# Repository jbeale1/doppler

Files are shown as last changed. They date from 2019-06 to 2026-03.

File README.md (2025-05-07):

## Doppler Radar object detection and speed measurement

This project uses cheap doppler radar modules: low power, short range motion detectors intended for automatic door openers and similar uses. The HB100 at 10.525 GHz or the smaller, more directional CDM324 at 24 GHz are available on eBay under $10 and Amazon for a bit more. They generate a weak (microphone-level) audio signal output, with a frequency proportional to the speed of the detected object. They can detect people to 25+ feet and cars to 100+ feet. Watch [this video](https://www.youtube.com/watch?v=r2NwtRPYWK4) to hear the signal as cars pass. A simple aluminum-foil horn antenna reduces sensitivity towards the side and back, and extends this range somewhat. Below is a CDM324 sensor in a small 3D printed conical horn, before applying the copper-foil tape for the reflector. The  sensor PCB is about 1 inch square. The horn front opening is 3 inches in diameter and when assembled, it picks up SUVs or trucks around 200 feet, somewhat less for small cars.

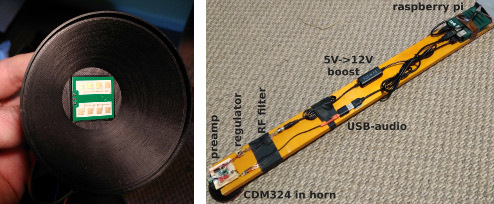
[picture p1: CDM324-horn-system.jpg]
CDM324_horn


When connecting a circuit, be careful because the output pin has a DC bias, and is static sensitive, and they will usually not survive being connected incorrectly. These modules run from +5V but there is no rejection of power-supply noise whatsoever, so it may deliver no useful signal with +5V straight from a USB or switching power supply. I suspect that is why many people quickly give up on them, not realizing how critical it is to have RF-clean power.  It works OK on battery power (4 NiMH AA cells is close enough to 5V), or a low-noise, RF-filtered supply. I start with a cheap noisy 5V->12V booster ("KUNCAN 5ft USB 5v to DC 12v Step Up") and put that 12V through several LC filters and ferrite beads, into a LM78L05 linear regulator to deliver reasonably clean +5V. The CDM324 draws around 30 mA at 5V.  Note the modules have a simple diode detector that will also respond to any strong local RF, so keep it away from your wifi hub and cellphone. There is a clear description of how the CDM324 works at [The Signal Path](http://thesignalpath.com/blogs/2018/08/12/tutorial-experiment-teardown-of-a-24ghz-doppler-radar-module/).

You can run the weak doppler output signal through a preamp (eg. opamp OPA209A, gain of 200x = 46 dB) and into a USB audio adaptor to get data into a Raspberry Pi (or any old phone/tablet/computer). On a Pi or other Linux based machine, **ffmpeg** can record the frequency signals into mp3 or wave files, and **sox** can generate a spectrogram. A car passing by at a constant speed will produce a curved line on the spectogram, because the signal is proportional to the relative *radial* velocity of the car at any given time. In other words, that part of the total velocity going directly towards or away from the sensor. 

For example, if the radar sensor sits by the side of the road looking to the right, and a car approaches from the right and then passes, at first the car's motion is almost directly towards the sensor (radial velocity ~ total velocity) but then radial velocity drops to zero at the moment it draws even with the sensor and passes by. After that its radial velocity goes negative as it receeds, but meanwhile it has also passed behind the sensor and out of the radar antenna pattern, so the signal fades out at some point before reaching a frequency of 0 (not to mention the preamp is AC-coupled). On a two-lane road, signals from oncoming traffic in the far lane fade into the noise sooner than with-traffic in the near lane, since cars in the far lane remain farther away as they pass.

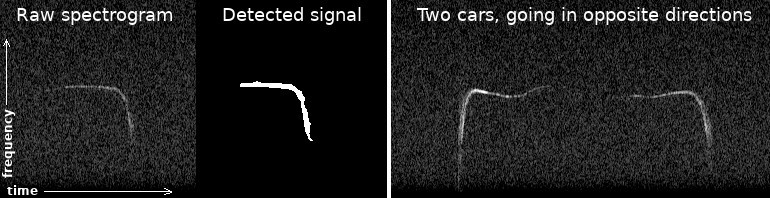
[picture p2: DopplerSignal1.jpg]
CarDopplerSignal


These cheap radar sensors do not have an I+Q output but just a magnitude output, so you cannot directly tell apart approaching and receeding velocity. However if the sensor is pointed along the road, cars passing by towards the right and left will generate an "L" shaped curve in the spectrum with the horizontal part pointing right and left respectively, as they pass the sensor either at the start or the end of the time they are inside the sensor's field of view (see illustration above). In this way you can still tell the car's direction.  This assumes the car's speed is roughly constant; it can be harder to tell if a car slows down and stops while inside the field of view. Below is the signal from an approaching car which slows down nearly to a stop, then speeds up as it passes by. The first dip and rise is due to the car's actual speed changing, while the final dropoff is only from the angle relative to the sensor.

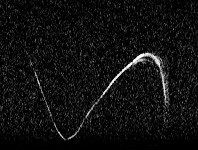
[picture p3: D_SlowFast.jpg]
SlowerThenFaster


If you had two sensors positioned back-to-back on the side of the road, so one was looking to the right and the other to the left, it would be easier to separate a change in speed from a change in heading angle. First one sensor would detect an approaching car until it passed by, and then the other sensor would see it receeding. Below is an illustration of this, where the two sensor outputs are color-coded and combined into one image. The true velocity of the car is most likely to be a smooth curve that bridges above the gap between the red and green curves (right- and left-facing sensor outputs).

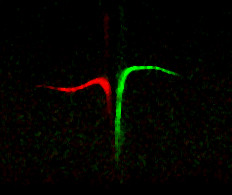
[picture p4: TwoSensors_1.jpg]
TwoSensors


Walkers or joggers generate a distictive wavy pattern (FM signal) in the spectrogram from the ~2 Hz motion of their arms and legs, and of course they move much slower than cars. As cars pass nearby the sensor, reflections from different parts of the rotating wheels generate some velocity spread. The top of the wheel is moving 2X the car speed, while the bottom of the wheel is momentarily near 0 speed. All such effects depend on reflectivity of the various parts so it is less visible on wheel hubs with a smoother profile.  If a vehicle is very close to the sensor while another one passes, you may get a signal from more than one angle at once, as part of the radar energy ping-pongs off one surface and then another.

Given that the green signal is from the left-pointing sensor, you can see below a person walking left to right at a steady pace (here, 4 mph). Later by a truck passes by going the same way. The truck speeds up slightly to 19 mph, then slows down quickly as it departs to the right.  There is a spike in the pedestrian signal just as he passes by. He was holding a cellphone in his hand and this may have been a momentary glint reflecting off the flat metal case.

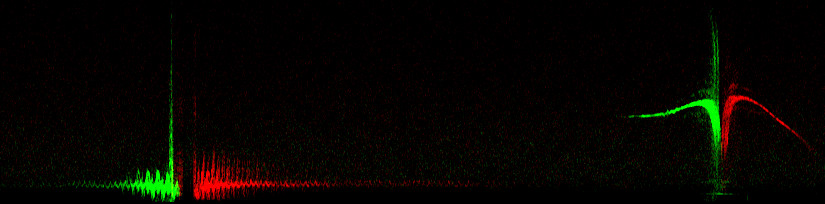
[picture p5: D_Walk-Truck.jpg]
Walk-Truck


If you have a sensor with both I/Q outputs (quadrature) you can directly detect the difference between motion toward and away from the sensor. This plot shows a spectrogram including negative frequencies, of the complex I/Q signal from a YH-24G01 24GHz module. This is me walking about 11 meters away and then back. I was careful to walk centered on-axis along the relatively tight antenna pattern of this module. The code which made this plot is "plotIQ.py" in this github directory.

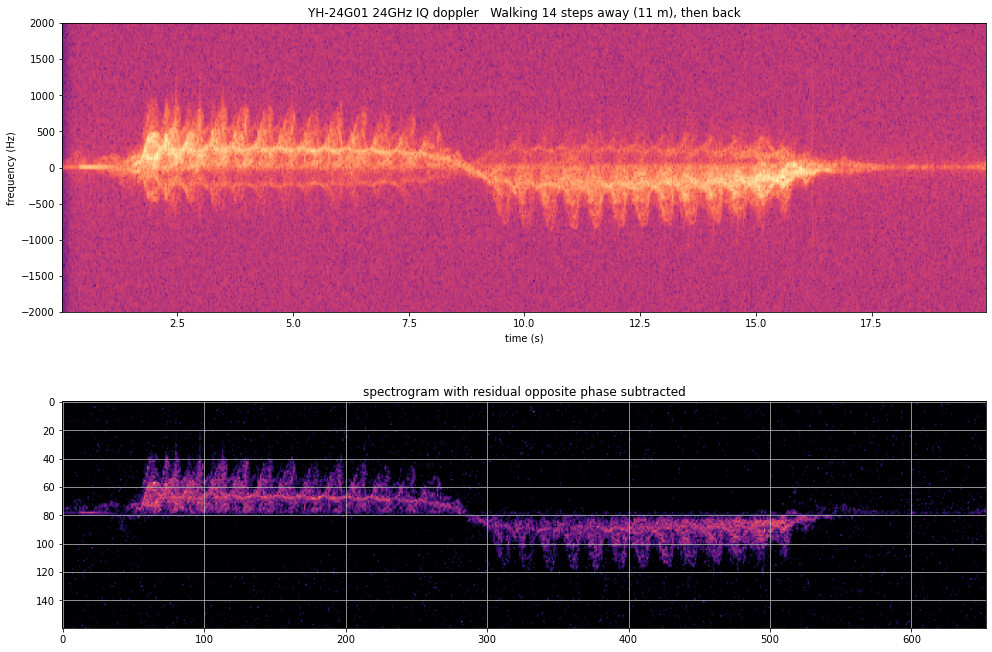
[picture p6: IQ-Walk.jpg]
Walk-IQ


The statistics of vehicle speeds over a day, on this particular road, is not well fitted to a single gaussian or normal distribution. There are a few cases at the high end around 70 km/h or 43 mph that are improbable outliers vs. the main population at 43 +/- 7 km/h  (or 27 mph +/- 4.4 mph).
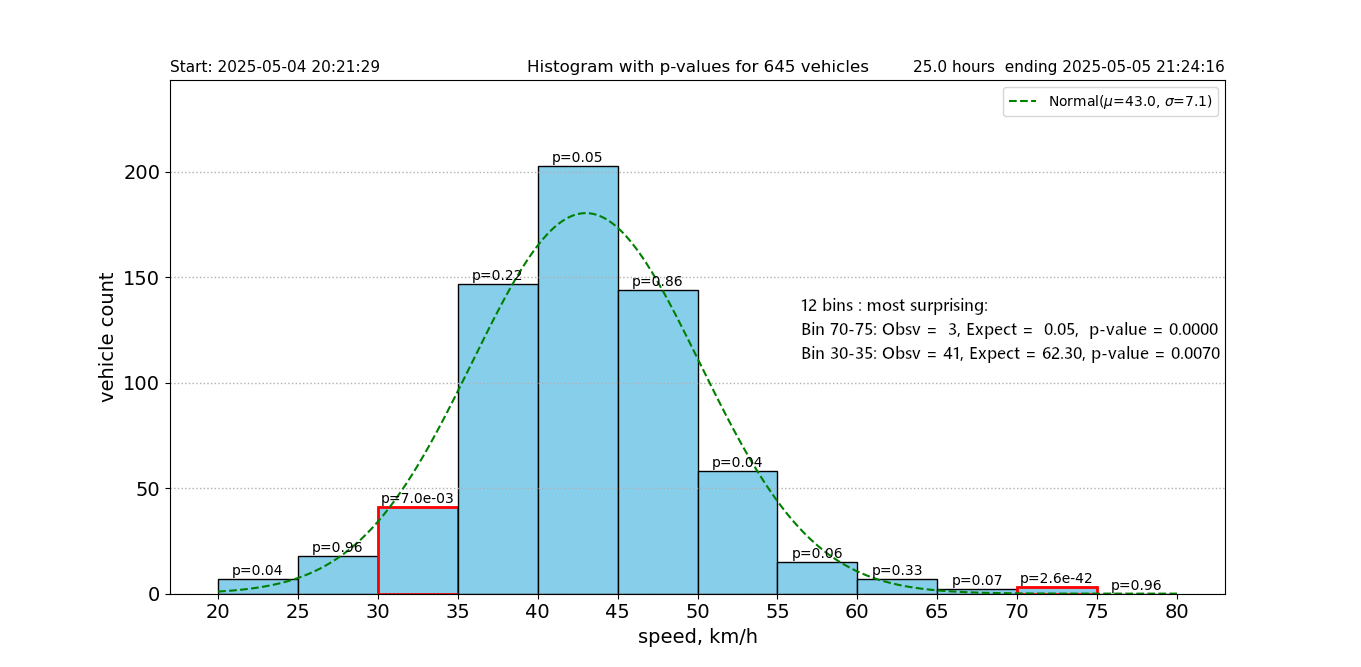
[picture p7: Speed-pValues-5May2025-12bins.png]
Speed-Histogram


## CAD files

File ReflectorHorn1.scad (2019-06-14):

// ===  rect -> circular horn antenna
// ===  J.Beale August 23 2018

e1 = 0.2;       // tolerance for ID shrink
OD1 = 75.4+e1;	// OD of "3-inch" round retroreflector
RFZ2 = 4.8;    // full z-height of round reflector
RFZ = 3.1;     // z-height step of round ref. edge
RFWT = 1;     // front lip wall thickness
ODFL = OD1 + (RFWT*2);  // OD of front lip
RFZE = 2;      // extra Z overlap with cone

e = 0.4;        // extra ID for slop
TXD = 25.2+e;	// Transmitter PCB X dim
TYD = 25.2+e;   // Transmitter PCB Y DIM
// OA1 = 36;     // opening angle of horn in degrees
OA1 = 55;     // opening angle of horn in degrees
TH1 = 0.8;    // wall thickness of horn

PCBZ = 6.8;     // z-height of PCB mounting
phX = 10;       // length of hole for PCB pins
phY = 4;        // width of hold for pins
phZ = 50;       // height of cutout block for pins
phYT = -10.4;   // Y axis translation of hole from center

PI = 3.14159265358979;  // constant
SQR2 = sqrt(2);  // constant
OD2 = TXD * SQR2;  // enclosing circle for PCB

OA1R = OA1 * PI / 180;  // angle in radians
ZH0 = (OD1/2) / tan(OA1/2);
ZHd = (OD2/2) / tan(OA1/2);
Zd = 3;  // vertical shift to create wall thickness
bt = 0.6; // bottom wall thickness
// =========================================
fn = 100;	// number of facets on cylinder
eps = 0.1; // a small number

// block to remove hole for PCB pins (3x on 0.1" centers)
module pcbHole() {
    translate([0,phYT,0])
      cube([phX,phY,phZ],center=true);
}

module cone1() {
    // front lip to hold edge of round cover
 difference() {
  translate([0,0,ZH0-ZHd-Zd-RFZE]) cylinder(d = ODFL, h = RFZ+RFZE, $fn=fn);   
  translate([0,0,ZH0-ZHd-Zd-eps]) cylinder(d = OD1, h = RFZ+2*eps, $fn=fn);   
 }

  translate([0,0,-ZHd-Zd+3.5]) {
    cylinder(d1 = 0, d2=ODFL, h=ZH0-5, center=false,$fn=fn); // outer conical shell
  }
}

module cone2() {
  translate([0,0,-ZHd]) {
    cylinder(d1 = 0, d2=OD1, h=ZH0, center=false,$fn=fn); // inner conical shell
  }
}

module shell1() {
    difference() {
        cone1();
        cone2();
    }
}

module bottom1() {
  translate([0,0,-PCBZ/2]) {
    cylinder(d=TXD*SQR2+Zd, h=PCBZ, center=true,$fn=fn); 
      // bottom pcb holder side  
  }
    
}

// ========================================

// round cover in front
// color("red") { translate([0,0,5+ZH0-ZHd-Zd]) cylinder(d = OD1, h = RFZ, $fn=fn);    }



module assy1() {


// main cone
intersection() {
  translate([0,0,+OD1/2]) cube([ODFL,ODFL,OD1],center=true);
  shell1();
 }

// bottom PCB holder    
difference() {
  bottom1();  // enclosing cylinder
  translate([0,0,bt-PCBZ/2]) cube([TXD,TYD,PCBZ],center=true); // pocket
  pcbHole();  // hole for pins
}
 
} // assy1()

intersection() {
  assy1();
  // translate([0,-100,-100])  cube([200,200,200]);
    
}

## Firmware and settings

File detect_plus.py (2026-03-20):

#!/usr/bin/env python3
"""
detect_plus.py  v1.12

Detects a "boxed plus" marker: a dark outer rectangle enclosing four white
corner squares arranged in a 2x2 grid, with the + shape formed by the dark
cross arms between them.

Detection pipeline:
  1. Preprocess: scale to 50%, light Gaussian blur, mild unsharp mask (USM)
     — used only for the coarse search step.
  2. Coarse: black-hat morphology on the 50% proc image finds dark-rectangle
     candidates in the road zone.
  3. Fine (_fine_detect_plus): for each candidate, crops the full-resolution
     gray image and applies adaptive threshold across a range of block sizes
     to isolate exactly four white corner squares as clean blobs.  The best-
     scoring 2x2 group is selected, subpixel corner refinement is applied to
     all 16 corners (4 squares x 4 corners), and the mean of the 4 inner
     corners gives an initial centre estimate.  The found group must be close
     to the candidate location and pass a size-uniformity check.
  4. Refine (refine_center_by_lines): re-detects the four white squares at
     full resolution using an adaptive block size scaled to the marker's
     apparent size.  Samples edge-gradient positions along each of the 8
     inner square edges (right/bottom of TL, left/bottom of TR, right/top
     of BL, left/top of BR), fits strictly parallel line pairs, and returns
     the mean of the 4 arm-line intersection points as the refined centre.
     Geometry sanity checks (square size uniformity, arm gap validity, and
     spatial ordering) reject false positives before the result is accepted.
  5. All returned coordinates are in original full-image pixels.

Can be run standalone:
    python detect_plus.py image.jpg [image2.jpg ...] [--verbose]

Or imported and called:
    from detect_plus import find_plus_markers
    results = find_plus_markers(gray, verbose=False)
"""

VERSION = "1.12"

import cv2
import numpy as np
import sys, os, argparse
from itertools import combinations

# ── Preprocessing ─────────────────────────────────────────────────────────────

def preprocess(gray, scale=0.5, blur_r=1, usm_radius=1, usm_amount=0.3):
    """
    Prepare image for plus-marker detection:
      1. Scale to `scale` (default 0.5 = 50%)
      2. Light Gaussian blur (blur_r pixel radius)
      3. Unsharp mask (usm_radius, usm_amount)

    The USM step dramatically clarifies the four white corner squares as
    isolated bright blobs on the dark + rectangle background.
    Returns the processed image at reduced scale.
    """
    small = cv2.resize(gray, None, fx=scale, fy=scale,
                       interpolation=cv2.INTER_AREA)
    if blur_r > 0:
        k = blur_r * 2 + 1
        small = cv2.GaussianBlur(small, (k, k), 0)
    blur_usm  = cv2.GaussianBlur(small, (usm_radius * 2 + 1, usm_radius * 2 + 1), 0)
    sharpened = cv2.addWeighted(small, 1.0 + usm_amount, blur_usm, -usm_amount, 0)
    return sharpened

# ── Geometry helpers (mirrors detect_marker.py) ──────────────────────────────

def _order_rect(pts):
    """Order 4 points as TL, TR, BR, BL."""
    pts = np.array(pts, dtype=np.float32)
    pts = pts[np.argsort(pts[:, 1])]
    top = pts[:2][np.argsort(pts[:2, 0])]
    bot = pts[2:][np.argsort(pts[2:, 0])]
    return np.array([top[0], top[1], bot[1], bot[0]], dtype=np.float32)


def _subpix_corners(gray, box, win=4):
    """Refine corner positions to sub-pixel accuracy."""
    h, w = gray.shape
    pts = np.clip(box, win + 1, min(h, w) - win - 2).astype(np.float32).reshape(-1, 1, 2)
    try:
        r = cv2.cornerSubPix(
            gray, pts, (win, win), (-1, -1),
            (cv2.TERM_CRITERIA_EPS + cv2.TERM_CRITERIA_MAX_ITER, 40, 0.001))
        return r.reshape(-1, 2)
    except cv2.error:
        return box


def _rect_corners_from_contour(c):
    """Return 4 ordered corners from a contour via minAreaRect."""
    rect = cv2.minAreaRect(c)
    box  = cv2.boxPoints(rect).astype(np.float32)
    return _order_rect(box)


# ── Coarse search ─────────────────────────────────────────────────────────────

def _coarse_candidates(proc, scale=0.5, tophat_k=5, thresh=15,
                       min_area=8, max_area=600, max_aspect=1.8):
    """
    Find candidate dark-rectangle centers in the preprocessed (50%) image
    using black-hat morphology. Returns (cx, cy) in ORIGINAL full-image coords.
    """
    kernel   = cv2.getStructuringElement(cv2.MORPH_RECT, (tophat_k, tophat_k))
    blackhat = cv2.morphologyEx(proc, cv2.MORPH_BLACKHAT, kernel)
    _, th    = cv2.threshold(blackhat, thresh, 255, cv2.THRESH_BINARY)

    contours, _ = cv2.findContours(th, cv2.RETR_EXTERNAL, cv2.CHAIN_APPROX_SIMPLE)
    hits = []
    for c in contours:
        area = cv2.contourArea(c)
        if not (min_area < area < max_area):
            continue
        rect = cv2.minAreaRect(c)
        rw, rh = rect[1]
        if rw < 1 or rh < 1:
            continue
        if max(rw, rh) / min(rw, rh) > max_aspect:
            continue
        cx, cy = rect[0]
        # Convert back to full-image coords
        hits.append((cx / scale, cy / scale))
    return hits


# ── Fine detection ────────────────────────────────────────────────────────────

def _fine_detect_plus(proc, cx_full, cy_full, scale=0.5, pad_full=120,
                      verbose=False):
    """
    Detect a boxed-plus marker near (cx_full, cy_full) in full-image coords.

    Despite the parameter name, `proc` is the 50%-scale preprocessed image
    used only to define the crop region; all detection runs on the full-
    resolution gray image passed to find_plus_markers (via gray captured in
    the closure — or via the `proc` image when called directly for testing).

    Crops a pad_fullxpad_full region around the candidate, applies adaptive
    threshold across block sizes (11,15) at 50% scale to find four white-
    square blobs in a 2x2 arrangement, scores all C(12,4)=495 quad
    combinations per threshold, subpixel-refines all 16 corners, and returns
    a result dict with centre, apparent size, and geometry.  The found group
    must be within 80% of pad_full of the candidate centre.

    All returned coordinates are in original full-image pixels.
    """
    h_proc, w_proc = proc.shape
    cx  = cx_full * scale
    cy  = cy_full * scale
    pad = int(pad_full * scale)

    x0 = max(0, int(cx) - pad)
    y0 = max(0, int(cy) - pad)
    x1 = min(w_proc, int(cx) + pad)
    y1 = min(h_proc, int(cy) + pad)
    crop = proc[y0:y1, x0:x1]
    if crop.size == 0:
        return None
    off_proc = np.array([x0, y0], dtype=np.float32)

    # Quick pre-check on first threshold: if there aren't at least 4 small
    # similarly-sized blobs, skip this candidate entirely — it can't be a + box.
    adapt0 = cv2.adaptiveThreshold(crop, 255,
                                    cv2.ADAPTIVE_THRESH_GAUSSIAN_C,
                                    cv2.THRESH_BINARY, 11, -5)
    ctrs0, _ = cv2.findContours(adapt0, cv2.RETR_EXTERNAL,
                                 cv2.CHAIN_APPROX_SIMPLE)
    small_blobs = [(cv2.contourArea(c), cv2.minAreaRect(c))
                   for c in ctrs0
                   if 5 < cv2.contourArea(c) < 800]
    small_blobs = [(a, r) for a, r in small_blobs
                   if r[1][0] >= 2 and r[1][1] >= 2
                   and max(r[1]) / min(r[1]) <= 3.0]
    if len(small_blobs) < 4:
        return None
    # Check uniformity: largest/smallest area ratio among top-4
    top4_areas = sorted([a for a,r in small_blobs], reverse=True)[:4]
    if top4_areas[-1] < 1 or top4_areas[0] / top4_areas[-1] > 8.0:
        return None

    # Adaptive threshold at 50% scale: sweep (block, C) pairs.
    # block=11 and block=15 are appropriate for white squares that are ~7-15px
    # at 50% scale (marker at 13-20m distance).  The best-scoring valid 2x2
    # group across all threshold settings is kept.
    best_group = None
    best_score = -1

    for block, C in [(11, 5), (15, 5), (11, 8), (15, 8)]:
        adapt = cv2.adaptiveThreshold(crop, 255,
                                       cv2.ADAPTIVE_THRESH_GAUSSIAN_C,
                                       cv2.THRESH_BINARY, block, -C)
        ctrs, _ = cv2.findContours(adapt, cv2.RETR_EXTERNAL,
                                    cv2.CHAIN_APPROX_SIMPLE)
        candidates = []
        for c in ctrs:
            area = cv2.contourArea(c)
            if not (5 < area < 2000):
                continue
            rect = cv2.minAreaRect(c)
            rw, rh = rect[1]
            if rw < 2 or rh < 2:
                continue
            if max(rw, rh) / min(rw, rh) > 3.0:
                continue
            candidates.append((area, rw, rh, rect[0], c))

        if len(candidates) < 4:
            continue

        top = sorted(candidates, key=lambda x: -x[0])[:12]
        for quad in combinations(range(len(top)), 4):
            group   = [top[k] for k in quad]
            centers = np.array([r[3] for r in group])
            xs = np.sort(centers[:, 0])
            ys = np.sort(centers[:, 1])
            x_spread = xs[3] - xs[0]
            y_spread = ys[3] - ys[0]
            if x_spread < 3 or y_spread < 3:
                continue
            # 2x2: gap between inner pair > 15% of spread
            if (xs[2]-xs[1]) < 0.15*x_spread or (ys[2]-ys[1]) < 0.15*y_spread:
                continue
            # Roughly square arrangement
            if max(x_spread, y_spread) / max(min(x_spread, y_spread), 1) > 3.5:
                continue
            # Similar areas
            areas = [r[0] for r in group]
            if max(areas) / max(min(areas), 1) > 3.0:
                continue
            # Similar widths
            widths = [max(r[1], r[2]) for r in group]
            if max(widths) / max(min(widths), 1) > 2.0:
                continue
            # Gap between children should be similar to child size
            # (arm width ≈ white square size in a well-designed + box)
            child_w = np.mean([max(r[1],r[2]) for r in group])
            child_h = np.mean([min(r[1],r[2]) for r in group])
            x_gap = xs[2] - xs[1]
            y_gap = ys[2] - ys[1]
            if not (0.3 < x_gap/max(child_w,1) < 5.0):
                continue
            if not (0.3 < y_gap/max(child_h,1) < 5.0):
                continue

            mean_area   = np.mean(areas)
            uniformity  = min(areas) / max(max(areas), 1)
            squareness  = min(x_spread, y_spread) / max(max(x_spread, y_spread), 1)
            score = mean_area*10 + uniformity*500 + squareness*200

            if score > best_score:
                best_score = score
                best_group = group

    if best_group is None:
        return None

    # The group's centre must be near the candidate location
    group_cx = np.mean([r[3][0] for r in best_group]) + x0
    group_cy = np.mean([r[3][1] for r in best_group]) + y0
    if abs(group_cx - cx_full) > pad * 0.8 or abs(group_cy - cy_full) > pad * 0.8:
        return None

    # Order spatially: by (y-bucket, x)
    best_group = sorted(best_group, key=lambda r: (round(r[3][1]/3), r[3][0]))

    child_corners_list = []
    for _, rw, rh, (rcx, rcy), c in best_group:
        box      = _rect_corners_from_contour(c)
        ref_proc = _subpix_corners(crop, box) + off_proc
        ref_full = ref_proc / scale
        child_corners_list.append(ref_full)

    all_corners = np.vstack(child_corners_list)   # 16x2 full-image coords
    child_sizes = [np.linalg.norm(c[1]-c[0]) for c in child_corners_list]
    half_csize  = np.mean(child_sizes) * 0.5

    x_min = all_corners[:,0].min() - half_csize
    x_max = all_corners[:,0].max() + half_csize
    y_min = all_corners[:,1].min() - half_csize
    y_max = all_corners[:,1].max() + half_csize
    outer_corners = np.array([[x_min,y_min],[x_max,y_min],
                               [x_max,y_max],[x_min,y_max]], dtype=np.float32)

    # apparent_px and wh_ratio based on child-centre span, not the padded outer
    # box.  The centre span scales cleanly with camera distance and is
    # independent of the half_csize padding, giving a stable size measure.
    child_centers = np.array([c.mean(axis=0) for c in child_corners_list])
    span_w = child_centers[:,0].max() - child_centers[:,0].min()
    span_h = child_centers[:,1].max() - child_centers[:,1].min()
    apparent_px = (span_w * span_h) ** 0.5
    if (apparent_px < 10 or apparent_px > 40):
        # Reject candidates with implausible apparent size (too small = far away,
        # too large = close but not detected in coarse search).
        return None
    wh_ratio    = span_w / span_h if span_h > 0 else 1.0

    # Center: mean of the 4 inner corners (the corners of each white square
    # that face the arm gap). These subpixel-refine to the arm-crossing point,
    # giving a more accurate center than the mean of all 16 corners.
    # Child order: [TL-child, TR-child, BL-child, BR-child]
    # Inner corner of each: BR(idx 2), BL(idx 3), TR(idx 1), TL(idx 0)
    inner_corners = np.array([
        child_corners_list[0][2],   # TL-child's BR
        child_corners_list[1][3],   # TR-child's BL
        child_corners_list[2][1],   # BL-child's TR
        child_corners_list[3][0],   # BR-child's TL
    ])
    center = inner_corners.mean(axis=0)

    # inner_mean: average gray of the four white squares in preprocessed image
    ccs = np.array([c.mean(axis=0) for c in child_corners_list])
    inner_mean = float(np.mean([
        proc[int(np.clip(pt[1]*scale, 0, h_proc-1)),
             int(np.clip(pt[0]*scale, 0, w_proc-1))]
        for pt in ccs]))

    return {
        'center':        center,
        'outer_corners': outer_corners,
        'child_corners': child_corners_list,
        'all_corners':   all_corners,
        'apparent_px':   apparent_px,
        'wh_ratio':      wh_ratio,
        'inner_mean':    inner_mean,
        'n_children':    4,
    }


# ── Line-intersection centre refinement ──────────────────────────────────────

def _nearest_odd(n):
    """Return nearest odd integer >= n, minimum 3."""
    n = max(3, int(n))
    return n if n % 2 == 1 else n + 1


def refine_center_by_lines(gray, result, hw=4, n_samples=30, trim=0.15):
    """
    Refine the + centre using edge-line fitting from full-resolution square
    bounding boxes.

    Re-detects the four white squares directly on the full-resolution gray
    image using adaptive threshold with block sizes scaled to the marker's
    apparent size (trying 2x and 3x the estimated square width, plus a fixed
    fallback of 21).  One erosion pass ensures bounding boxes sit inside the
    white regions rather than straddling the edges.

    For each of the 8 inner square edges (TL/BL right edges → V_left arm;
    TR/BR left edges → V_right arm; TL/TR bottom edges → H_top arm;
    BL/BR top edges → H_bot arm) samples edge-gradient positions along only
    that square's own span.  Fits a line to each set of samples, then enforces
    strict parallelism within each arm pair by averaging directions.  The
    final centre is the mean of the 4 arm-line intersection points.

    Before accepting the result, applies geometry sanity checks:
      — Four square areas within 4x of each other
      — Four square linear sizes within 2.5x of each other
      — Both arm gaps positive (no overlap)
      — Both arm gaps ≤ 3x average square size
      — H and V arm gaps within 5x of each other
      — Spatial ordering valid: TL.x < TR.x, BL.x < BR.x,
        TL.y < BL.y, TR.y < BR.y

    Returns updated result dict with 'center' replaced by the refined value,
    '_squares_bbox', '_lines', and '_crossings' added.  Returns the original
    result unchanged (without '_squares_bbox') if any check fails, allowing
    the caller to detect and reject the candidate.
    """
    # ── Re-detect white squares at full resolution ────────────────────────────
    gray_full = gray
    cx_est = float(result['center'][0])
    cy_est = float(result['center'][1])

    # Scale the crop pad with the apparent marker size so we always have
    # enough margin even for larger (closer) markers.
    apparent = result.get('apparent_px', 25)
    # apparent_px is child-centre span ≈ arm_pitch.
    # Each white square ≈ apparent/1.5 px wide at full res.
    # Pad needs to comfortably contain 2 squares + arm gap on each side.
    pad = max(55, int(apparent * 3.5))
    x0 = max(0, int(cx_est) - pad)
    y0 = max(0, int(cy_est) - pad)
    x1 = min(gray_full.shape[1], int(cx_est) + pad)
    y1 = min(gray_full.shape[0], int(cy_est) + pad)
    crop = gray_full[y0:y1, x0:x1]
    if crop.size == 0:
        return result

    # Adaptive threshold block size must be larger than one white square
    # but smaller than two squares.  Estimated white square width ≈ apparent/1.5.
    # Try several block sizes from small to large; keep whichever finds 4 squares.
    sq_est = max(5, int(apparent / 1.5))
    block_sizes = sorted(set([
        _nearest_odd(sq_est * 2 + 1),   # ~2x square width
        _nearest_odd(sq_est * 3 + 1),   # ~3x square width
        21,                              # fixed fallback
    ]))

    squares = []
    for block in block_sizes:
        adapt = cv2.adaptiveThreshold(crop, 255,
                                       cv2.ADAPTIVE_THRESH_GAUSSIAN_C,
                                       cv2.THRESH_BINARY, block, -8)
        adapt = cv2.erode(adapt, np.ones((3,3), np.uint8), iterations=1)
        ctrs, _ = cv2.findContours(adapt, cv2.RETR_EXTERNAL,
                                    cv2.CHAIN_APPROX_SIMPLE)
        cands = []
        for c in ctrs:
            area = cv2.contourArea(c)
            if not (20 < area < 5000): continue
            rect = cv2.minAreaRect(c)
            rw, rh = rect[1]
            max_sq_px = sq_est * 3
            if not (4 < rw < max_sq_px and 4 < rh < max_sq_px): continue
            if max(rw, rh) / min(rw, rh) > 2.5: continue
            bx, by, bw, bh = cv2.boundingRect(c)
            cx_f, cy_f = bx + x0 + bw // 2, by + y0 + bh // 2
            cands.append((area, c, rect, bx+x0, by+y0, bw, bh, cx_f, cy_f))
        cands.sort(key=lambda s: (round(s[8] / 10), s[7]))
        if len(cands) >= 4:
            squares = cands
            break   # found enough with this block size

    squares.sort(key=lambda s: (round(s[8] / 10), s[7]))
    if len(squares) != 4:
        return result   # can't refine

    tl, tr, bl, br = squares   # each: (area, c, rect, bx, by, bw, bh, cx, cy)

    # Validate spatial ordering: after sorting, TL must be left of TR,
    # BL must be left of BR, and top row must be above bottom row.
    # If violated the four blobs are not in a genuine 2x2 arrangement.
    if tl[7] >= tr[7]:   # TL.cx >= TR.cx
        return result
    if bl[7] >= br[7]:   # BL.cx >= BR.cx
        return result
    if tl[8] >= bl[8]:   # TL.cy >= BL.cy
        return result
    if tr[8] >= br[8]:   # TR.cy >= BR.cy
        return result

    # ── Sample edge-gradient positions along each inner rectangle edge ────────
    def sample_edge(x_range, y_fixed, direction):
        """
        Vectorized edge-gradient sampler. Builds the full pixel-sample grid
        as numpy arrays instead of a Python loop, making it ~10x faster.
        """
        if direction == 'h':
            p1 = np.array([float(x_range[0]), float(y_fixed)])
            p2 = np.array([float(x_range[1]), float(y_fixed)])
            perp_idx = 1    # gradient measured in y
        else:
            p1 = np.array([float(y_fixed), float(x_range[0])])
            p2 = np.array([float(y_fixed), float(x_range[1])])
            perp_idx = 0    # gradient measured in x
        L = np.linalg.norm(p2 - p1)
        if L < 2: return None
        tang = (p2 - p1) / L

        # Sample positions along the edge
        ts = np.linspace(trim * L, (1 - trim) * L, n_samples)
        base_pts = p1 + ts[:, None] * tang    # (n_samples, 2)

        # Perpendicular offsets
        ds = np.linspace(-hw, hw, hw * 4 + 1)  # (n_d,)
        # All sample coords: (n_samples, n_d, 2)
        if direction == 'h':
            xs = np.round(base_pts[:, 0]).astype(int)             # (n,)
            ys = np.round(base_pts[:, 1:2] + ds[None, :]).astype(int)  # (n, n_d)
            # Clip to image bounds
            xs_c = np.clip(xs, 0, gray_full.shape[1]-1)
            ys_c = np.clip(ys, 0, gray_full.shape[0]-1)
            valid = (ys >= 0) & (ys < gray_full.shape[0])
            vals  = gray_full[ys_c, xs_c[:, None]].astype(float)  # (n, n_d)
        else:
            ys = np.round(base_pts[:, 1]).astype(int)
            xs = np.round(base_pts[:, 0:1] + ds[None, :]).astype(int)
            xs_c = np.clip(xs, 0, gray_full.shape[1]-1)
            ys_c = np.clip(ys, 0, gray_full.shape[0]-1)
            valid = (xs >= 0) & (xs < gray_full.shape[1])
            vals  = gray_full[ys_c[:, None], xs_c].astype(float)

        vals[~valid] = np.nan

        # For each sample position, find edge via gradient-weighted centroid
        pts = []
        for i in range(n_samples):
            v = vals[i]
            ok = ~np.isnan(v)
            if ok.sum() < 3: continue
            v_clean = np.where(ok, v, np.nanmean(v))
            g = np.abs(np.gradient(v_clean))
            if g.sum() < 1: continue
            d_e = float((g * ds).sum() / g.sum())
            pt = base_pts[i].copy()
            pt[perp_idx] += d_e
            pts.append(pt)
        return np.array(pts, np.float32) if len(pts) >= 3 else None

    def fit_line(pts):
        res = cv2.fitLine(pts, cv2.DIST_L2, 0, 0.01, 0.01).flatten()
        return (np.array([float(res[2]), float(res[3])]),
                np.array([float(res[0]), float(res[1])]))

    def avg_dir(d1, d2):
        if np.dot(d1, d2) < 0: d2 = -d2
        d = d1 + d2; return d / np.linalg.norm(d)
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

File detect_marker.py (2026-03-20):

#!/usr/bin/env python3
"""
detect_marker.py  v1.0

Locates printed tracking markers in a full 1920x1080 image for camera calibration purposes.
Uses a coarse-to-fine pipeline:
  1. Coarse (1/4 scale): tophat morphology finds bright compact rectangles
  2. Verify: nested contour structure (CLAHE + multi-threshold) confirms identity
  3. Fine:   homography + subpixel refinement of all features
  4. Validate: white-field uniformity, apparent size, inlier count, road zone

Usage:
    python detect_marker.py image.jpg [image2.jpg ...] [options]
    python detect_marker.py /path/to/frame/directory/ [options]

Options:
    --verbose       Print all candidates and rejection reasons
    --max-dist N    Maximum detection distance in meters (default: 25.0)
    --debug         Save annotated debug crops

Changelog:
    v1.0  Duplicate detection resolved by quality comparison
          (n_inliers then wh_ratio); better of two overlapping
          detections kept; printing deferred until after all candidates
          processed; --road-x argument added.
    v0.9  Width/height ratio check (w/h >= 0.80) rejects tall/narrow spurious
          detections; adaptive ID fill threshold (white_level * 0.70, fallback 110);
          max apparent size raised to 135px; contour scoring uses squareness not area.
    v0.6  Adaptive ID fill threshold; road zone default 33%-48% of height;
          --road-y argument for per-camera tuning; median white_level.
    v0.5  Multi-threshold binary selection; max apparent size gate;
          road-zone center check; relaxed inlier count for small markers;
          directory input support; distance reporting.
    v0.4  White-field uniformity filter (wf_mean, wf_smooth).
    v0.3  CLAHE preprocessing; dense grid fallback; --verbose flag.
    v0.2  SuperPoint-style nested contour hierarchy; homography fit.
    v0.1  Initial release.
"""

VERSION = "1.0"

import cv2
import numpy as np
import sys, os, argparse, warnings
warnings.filterwarnings('ignore', category=RuntimeWarning)

# ── Camera calibration ───────────────────────────────────────────────────────
# Inner border real-world size: 672/850 * 17 inches (2x2 tiled poster)
MARKER_REAL_M    = (672 / 850) * 17 * 0.0254   # 0.3414 m
# Focal length derived from known-distance calibration frame
# (58.930 px apparent size at 14.557 m)
FOCAL_LENGTH_PX  = 58.930 * 14.557 / MARKER_REAL_M   # 2512.89 px
# Set to None to suppress distance output if not yet calibrated
# FOCAL_LENGTH_PX = None

# Maximum valid detection distance in meters.
# At 25m the marker is ~34px apparent size — beyond this false positives
# from small scene features increase sharply.
MAX_DISTANCE_M  = 25.0
MIN_APPARENT_PX = MARKER_REAL_M * FOCAL_LENGTH_PX / MAX_DISTANCE_M  # ~34 px
SVG_TL  = np.array([89., 189.])
SVG_W   = SVG_H = 672.0

def _n(pt):  # normalise to [0,1]
    return [(pt[0]-SVG_TL[0])/SVG_W, (pt[1]-SVG_TL[1])/SVG_H]

CANON_CORNERS  = np.array([[0,0],[1,0],[1,1],[0,1]], dtype=np.float32)
CANON_DOTS     = np.array([_n([x,y]) for y in [390,590]
                                      for x in [225,425,625]], dtype=np.float32)
CANON_ID_CELLS = [
    {'name':'left',
     'corners': np.array([_n([133,730]),_n([373,730]),
                           _n([373,820]),_n([133,820])], dtype=np.float32)},
    {'name':'right',
     'corners': np.array([_n([477,730]),_n([717,730]),
                           _n([717,820]),_n([477,820])], dtype=np.float32)},
]

# ── Helpers ──────────────────────────────────────────────────────────────────

def order_corners(pts):
    pts = np.array(pts, dtype=np.float32)
    pts = pts[np.argsort(pts[:,1])]
    top = pts[:2][np.argsort(pts[:2,0])]
    bot = pts[2:][np.argsort(pts[2:,0])]
    return np.array([top[0],top[1],bot[1],bot[0]], dtype=np.float32)

def project(H, pts):
    ph = np.hstack([pts, np.ones((len(pts),1))]).T
    pr = H @ ph;  pr /= pr[2]
    return pr[:2].T

def refine_centroid(gray, cx, cy, r=6):
    x0,y0   = int(cx)-r, int(cy)-r
    x0c,y0c = max(0,x0),  max(0,y0)
    x1c,y1c = min(gray.shape[1],x0+2*r+1), min(gray.shape[0],y0+2*r+1)
    patch    = gray[y0c:y1c, x0c:x1c].astype(np.float64)
    med = np.median(patch)
    w   = np.where(patch < med, med-patch, 0.0)
    tot = w.sum()
    if tot < 1: return cx, cy
    rows,cols = np.mgrid[0:patch.shape[0], 0:patch.shape[1]]
    return (w*cols).sum()/tot + x0c, (w*rows).sum()/tot + y0c

def subpix(gray, box):
    h,w = gray.shape
    cf  = np.clip(box, 2, min(h,w)-3).astype(np.float32).reshape(-1,1,2)
    try:
        r = cv2.cornerSubPix(gray, cf, (3,3), (-1,-1),
            (cv2.TERM_CRITERIA_EPS+cv2.TERM_CRITERIA_MAX_ITER, 40, 0.001))
        return r.reshape(-1,2)
    except cv2.error:
        return box

# ── Stage 1: coarse detection at 1/4 scale ───────────────────────────────────

def coarse_candidates(gray, coarse_scale=0.25,
                      tophat_k=5, thresh=10,
                      min_area=10, max_area=800,
                      max_aspect=2.0):
    """
    Return list of (cx, cy) in FULL image coords for candidate marker centers.
    Uses white tophat to find compact bright rectangles.
    """
    small  = cv2.resize(gray, None, fx=coarse_scale, fy=coarse_scale,
                        interpolation=cv2.INTER_AREA)
    kernel = cv2.getStructuringElement(cv2.MORPH_RECT, (tophat_k, tophat_k))
    tophat = cv2.morphologyEx(small, cv2.MORPH_TOPHAT, kernel)
    _, th  = cv2.threshold(tophat, thresh, 255, cv2.THRESH_BINARY)

    contours, _ = cv2.findContours(th, cv2.RETR_EXTERNAL, cv2.CHAIN_APPROX_SIMPLE)
    hits = []
    for c in contours:
        area = cv2.contourArea(c)
        if not (min_area < area < max_area): continue
        rect       = cv2.minAreaRect(c)
        rw, rh     = rect[1]
        if rw < 1 or rh < 1: continue
        if max(rw,rh)/min(rw,rh) > max_aspect: continue
        cx, cy = rect[0]
        hits.append((cx / coarse_scale, cy / coarse_scale))

    # Sort by proximity to horizontal center of image (vehicles pass through center)
    ih, iw = gray.shape
    img_cx = iw / 2
    hits.sort(key=lambda p: abs(p[0] - img_cx))
    return hits

# ── Stage 2: fine detection in a crop around a candidate ─────────────────────
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

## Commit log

2019-06-14 CDM324 in 3D printed cone, before Cu tape
2019-06-14 small horn antenna for CDM324 radar
    [ReflectorHorn1.scad]
2019-06-14 CDM324 horn, and assembled system
2019-06-14 sensor horn and entire system
2019-06-22 two sensors, red/green, time-aligned
2022-11-10 read HLK-LD303-24G doppler occupancy sensor
2023-01-08 mask off noise, save image
    [IQ-plot1.py]
2023-01-12 undo batch processing, had memory leak (!?)
    [IQ-plot1.py]
2023-01-12 rm files when done, avoid filling temp dir
    [batch-proc-IQ.py]
2023-01-15 bugfix for noise autoscaling too high
    [IQ-plot1.py]
2023-01-15 bugfix; now uses fixed range
    [IQ-plot1.py]
2023-01-25 gaussian smoothing + noise thresholding
    [IQ-plot1.py]
2025-05-09 improve noise filtering
2025-05-09 do not print surprising bins, if none are
